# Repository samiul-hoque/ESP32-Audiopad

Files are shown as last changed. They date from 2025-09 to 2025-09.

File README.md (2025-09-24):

# ESP32-Audiopad

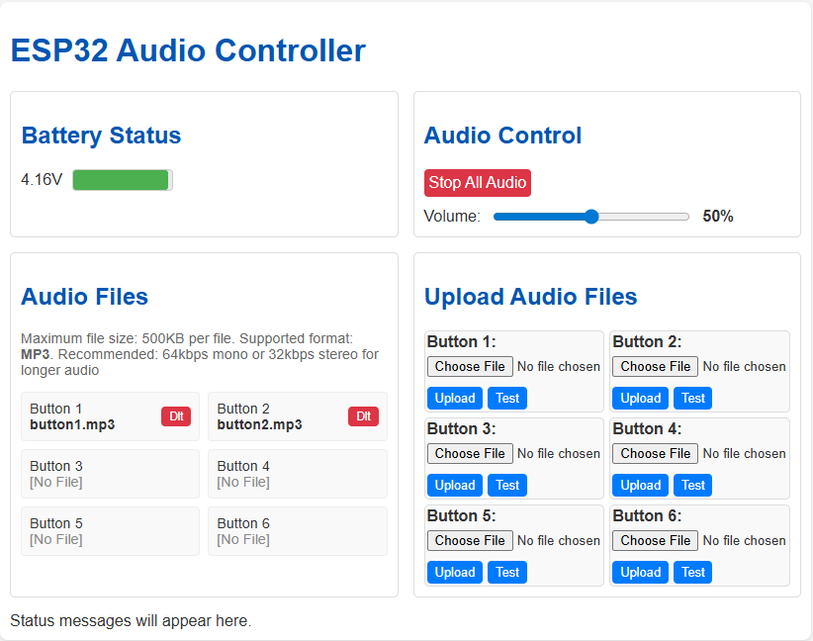
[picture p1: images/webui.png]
ESP32 Audiopad


A WiFi-enabled, web-configurable audio playback device using an ESP32. This project turns an ESP32 into a simple soundboard that plays specific MP3 files when physical buttons are pressed. All configuration, file management, and testing can be done through a web interface hosted on the device itself.

## Features

*   **6-Button Audio Playback:** Connect up to 6 physical buttons to trigger MP3 playback.
*   **Web-Based Management:** No need to re-flash to change sounds. Connect to the ESP32's web server to:
    *   Upload MP3 files for each button.
    *   Delete assigned audio files.
    *   View currently assigned files.
    *   Monitor battery voltage.
    *   Remotely test button sounds.
    *   Stop any currently playing audio.
*   **Over-The-Air (OTA) Updates:** Update the firmware and filesystem (SPIFFS) over WiFi using the Arduino IDE.
*   **Deep Sleep:** Automatically enters deep sleep after a period of inactivity to conserve battery, and wakes up on a button press.
*   **I2S Audio Output:** Uses an I2S amplifier for clear digital audio playback.
*   **Battery Monitoring:** Reads voltage from an ADC pin to provide a battery level estimate on the web UI.

## Hardware Requirements

*   **ESP32 Development Board:** Any standard ESP32 board should work.
*   **I2S Audio Amplifier:** MAX98357A has been used.
*   **Speaker:** 3W speaker.
*   **Push Buttons (x6):** Cherry MX Red buttons.
*   **Resistors:** External pull-up resistors are needed for deep sleep functionality to save battery.
*   **Battery:** 1650 Lithium Ion battery with BMS
*   **Wires and a breadboard/protoboard.**

### Pinout

The following pin connections are defined in the code.

| Component | ESP32 Pin | Description |
| --- | --- | --- |
| **I2S Amplifier** | | |
| `BCLK` | 4 | Bit Clock |
| `LRC` / `WS` | 2 | Left/Right Clock (Word Select) |
| `DIN` | 15 | Data In |
| **Buttons** | |10k External Pull-up Resistors used |
| Button 1 | 25 | |
| Button 2 | 26 | |
| Button 3 | 27 | |
| Button 4 | 13 | |
| Button 5 | 14 | |
| Button 6 | 32 | |
| **Battery** | | For voltage monitoring |
| `BATTERY_PIN` | 35 | Connect to the positive terminal |

> **Note:** The code is currently configured for buttons with external pull-up resistors (`pinMode(PIN, INPUT)`). The current debounce logic works for a button press pulling the pin LOW.

## Software Setup

1.  **Arduino IDE:** Make sure you have the Arduino IDE installed with the ESP32 board support package.

2.  **Libraries:** Install the following libraries through the Arduino Library Manager:
    *   `ESP8266Audio` by Earle F. Philhower, III (works for ESP32 as well)
    *   `WebServer` (part of the ESP32 core)
    *   `SPIFFS` (part of the ESP32 core)

3.  **WiFi Credentials:**
    *   Create a file named `secrets.h` in the same directory as your `.ino` file.
    *   Add your WiFi network credentials to this file like so:

    ```cpp
    // secrets.h
    #pragma once

    const char* ssid = "YOUR_WIFI_SSID";
    const char* password = "YOUR_WIFI_PASSWORD";
    ```
    *   The `secrets.h` file is included in `.gitignore` to prevent you from accidentally committing your credentials.

4.  **Upload Filesystem:**
    *   Before the first flash, you need to upload the filesystem image. In the Arduino IDE, go to `Tools` > `Partition Scheme` and select a scheme with SPIFFS, like "Default 4MB with spiffs (1.2MB APP/1.5MB SPIFFS)".
    *   If you have a `data` directory with files to pre-load, you can use the "ESP32 Sketch Data Upload" tool. For this project, it's not necessary as the web interface creates the `/audio` directory.

5.  **Compile and Flash:**
    *   Select your ESP32 board and COM port from the `Tools` menu.
    *   Click the "Upload" button to flash the firmware to your ESP32.

## How to Use

1.  **Power On:** Power up your ESP32. It will automatically connect to the WiFi network you specified in `secrets.h`.

2.  **Find IP Address:** Open the Arduino IDE's Serial Monitor (baud rate 115200). The ESP32 will print its IP address once connected to WiFi.

3.  **Open Web Interface:** Open a web browser on a device connected to the same network and navigate to the ESP32's IP address (e.g., `http://192.168.1.123`).

4.  **Upload Audio:**
    *   The web page will show an upload section for each of the 6 buttons.
    *   Click "Choose File" for a button, select an MP3 file from your computer, and click "Upload".
    *   The file will be named `buttonX.mp3` (where X is the button number) and stored in the ESP32's filesystem.
    *   **Note:** There is a file size limit of 500KB per file. For best results, use MP3s with a lower bitrate (e.g., 64kbps mono).

5.  **Play Sounds:**
    *   Press a physical button connected to the ESP32 to play its assigned sound.
    *   You can also use the "Test" button on the web interface to trigger playback remotely.

6.  **Manage Files:**
    *   The "Audio Files" section shows which buttons have a sound assigned.
    *   You can delete any sound file by clicking the "Delete" button next to it.

## Future Improvements
*   Add a visual indicator (e.g., an LED) to show when the device is going to sleep.
*   Implement a "Settings" page in the web UI to configure sleep timeout and other parameters.

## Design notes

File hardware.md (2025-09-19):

# Pin Definitions

## Battery
BATTERY_PIN 35
ADC_TO_VOLT 7.445f / 4096.0f 

## Buttons
buttonPins[] = {25, 26, 27, 13, 14, 32};

## Amp
BCLK = 4
LRC = 2
DIN = 15

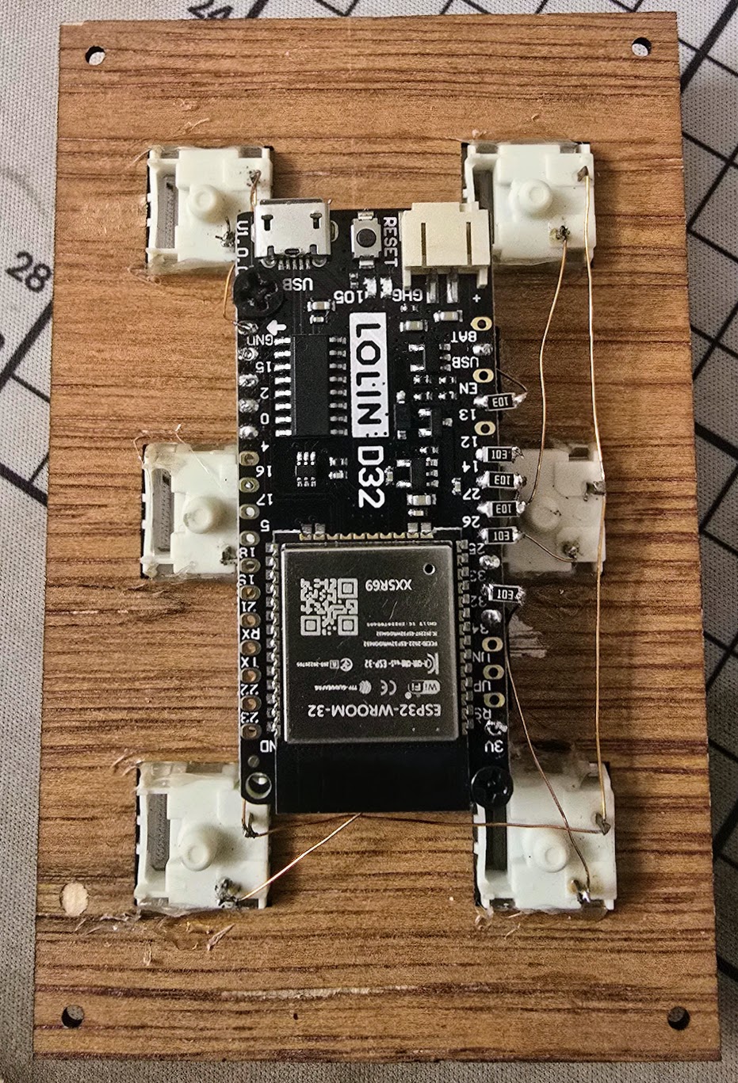
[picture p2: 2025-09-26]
images/Electronics.jpg

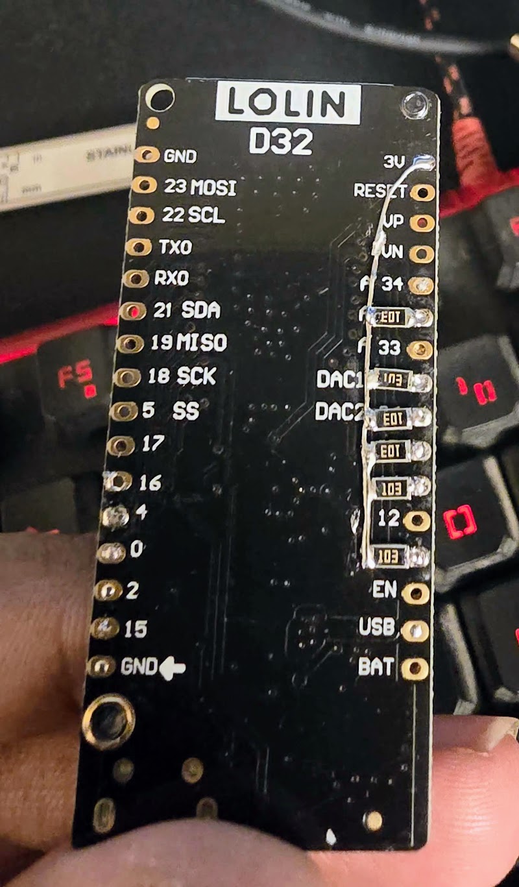
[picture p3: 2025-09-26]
images/10k external pull up resistors for RTCGPIO.jpg

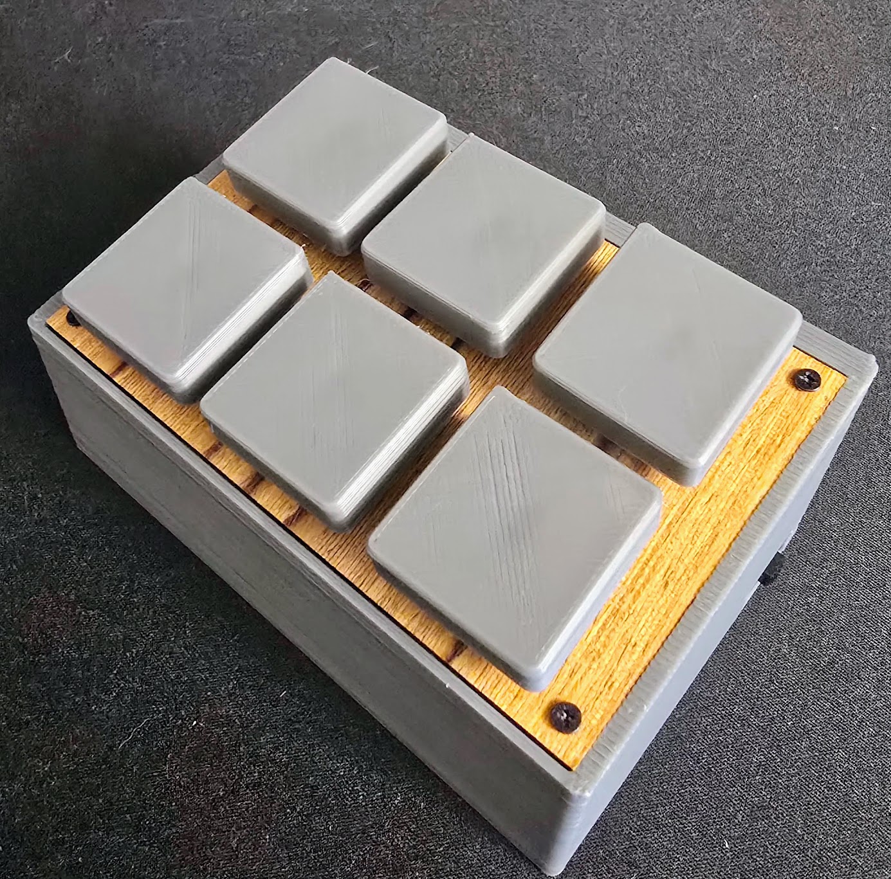
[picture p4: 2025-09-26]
images/ESP32AudioPad.jpg

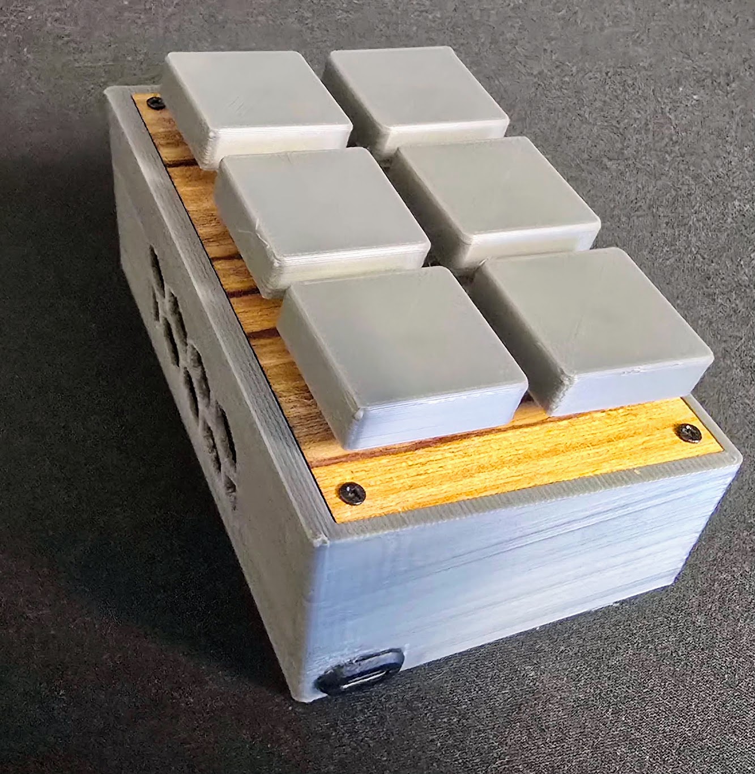
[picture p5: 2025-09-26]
images/ESP32AudioPad2.jpg

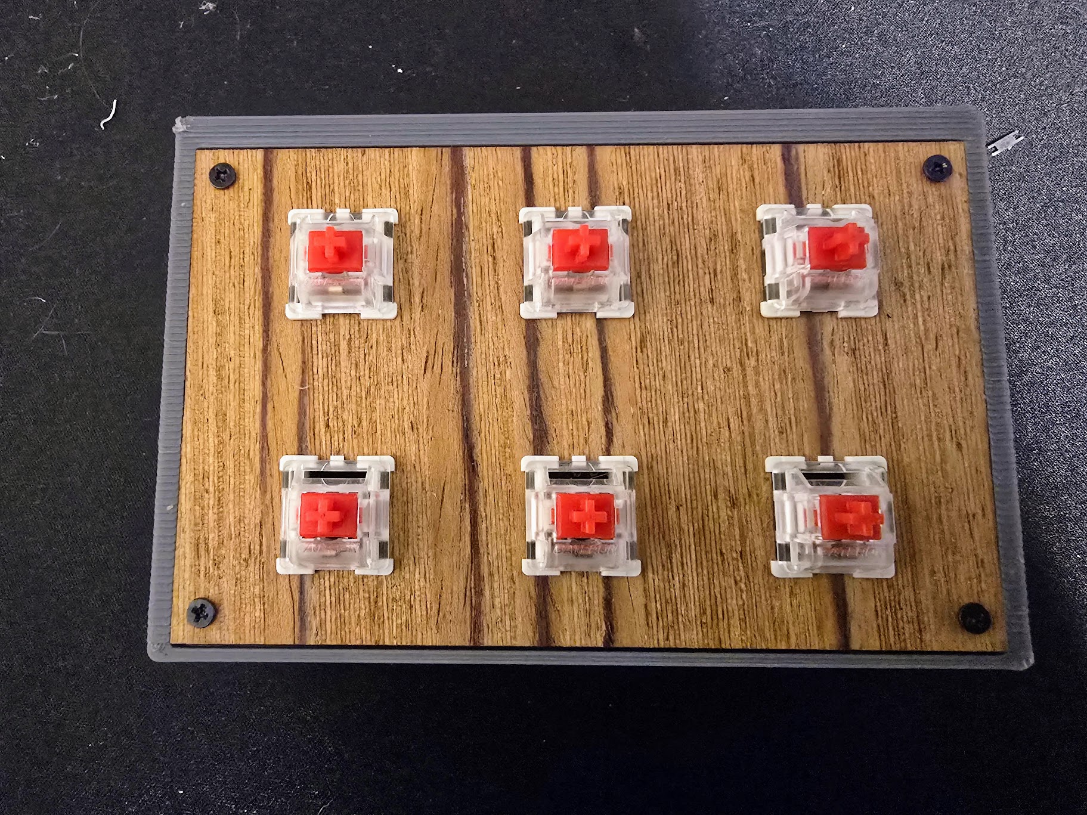
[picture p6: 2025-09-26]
images/ESP32AudioPad3.jpg

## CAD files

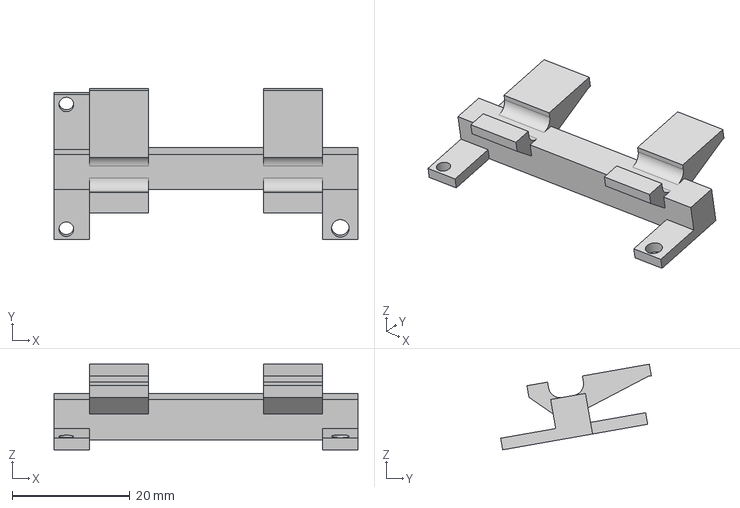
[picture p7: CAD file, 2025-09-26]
3D Files/ESP-d32 holder.step
51.6 x 25.6 x 14.5 mm

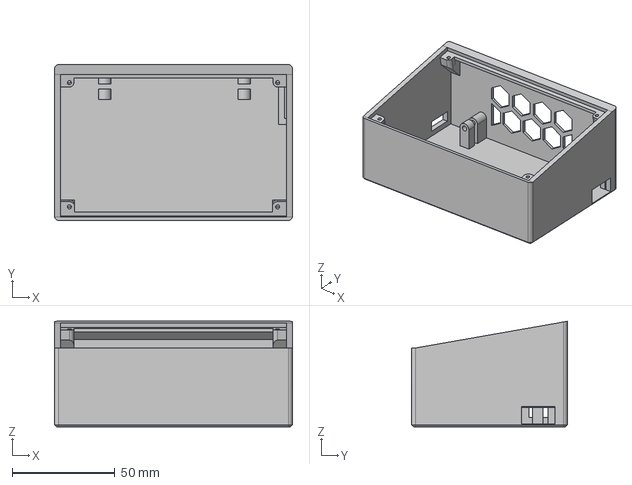
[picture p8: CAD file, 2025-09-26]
3D Files/Base.step
116.0 x 75.9 x 51.5 mm

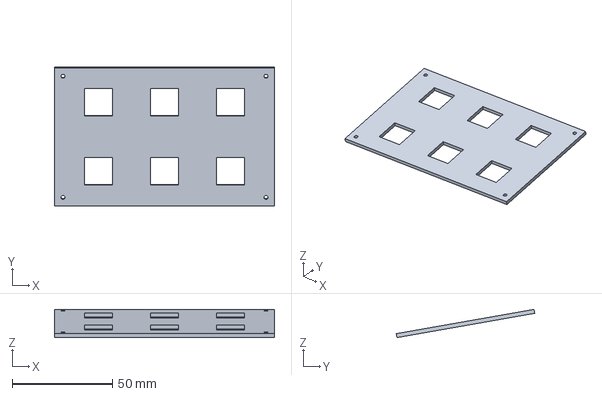
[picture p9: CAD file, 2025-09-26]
3D Files/Top.step
110.0 x 69.3 x 14.1 mm

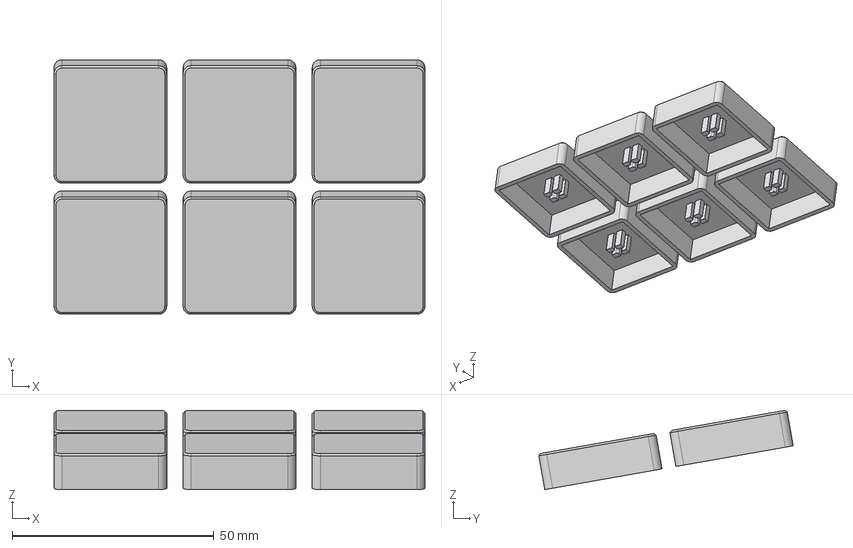
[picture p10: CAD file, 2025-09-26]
3D Files/Buttons.step
92.0 x 63.1 x 19.6 mm

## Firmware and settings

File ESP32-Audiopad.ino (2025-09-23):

#include <WiFi.h>
#include <SPIFFS.h>
#include "secrets.h"

// Include all our custom headers
#include "config.h"
#include "button_manager.h"
#include "audio_manager.h"
#include "web_server.h"
#include "ota_manager.h"
#include "power_manager.h"

// Create instances of our managers
ButtonManager buttonManager;
AudioManager audioManager;
WebServerManager webServer;
OTAManager otaManager;
PowerManager powerManager;

// Timing variables for power management
unsigned long lastActivityCheck = 0;

// Callback functions
void onButtonPressed(int buttonNum) {
    powerManager.updateActivity(); // Update activity on button press
    audioManager.playButtonSound(buttonNum);
}

void onTestButtonPressed(int buttonNum) {
    powerManager.updateActivity(); // Update activity on web test
    audioManager.playButtonSound(buttonNum);
}

void onStopAudio() {
    powerManager.updateActivity(); // Update activity on stop command
    audioManager.stopCurrentAudio();
}

void onSetVolume(float volume) {
    powerManager.updateActivity(); // Update activity on volume change
    audioManager.setVolume(volume);
}

float onGetVolume() {
    powerManager.updateActivity(); // Update activity on volume request
    return audioManager.getVolume();
}

void setup() {
    Serial.begin(115200);
    
    // Initialize power management first (handles wake up reasons)
    powerManager.init();
    
    // Initialize SPIFFS
    if(!SPIFFS.begin(true)) {
        Serial.println("SPIFFS Mount Failed");
        return;
    }
    
    // Create audio directory if it doesn't exist
    if (!SPIFFS.exists("/audio")) {
        SPIFFS.mkdir("/audio");
    }

    // Print SPIFFS info
    size_t totalBytes = SPIFFS.totalBytes();
    size_t usedBytes = SPIFFS.usedBytes();
    Serial.printf("SPIFFS Total: %d bytes, Used: %d bytes, Free: %d bytes\n", 
                  totalBytes, usedBytes, totalBytes - usedBytes);
    
    // Initialize battery pin
    pinMode(BATTERY_PIN, INPUT);
    
    // Initialize all managers
    buttonManager.init();
    audioManager.init();
    
    // Set up button callback
    buttonManager.onButtonPressed = onButtonPressed;
    
    // Connect to WiFi
    WiFi.begin(ssid, password);
    while (WiFi.status() != WL_CONNECTED) {
        delay(1000);
        Serial.println("Connecting to WiFi...");
    }
    Serial.println("WiFi connected!");
    Serial.print("IP address: ");
    Serial.println(WiFi.localIP());
    
    // Update activity after WiFi connection
    powerManager.updateActivity();
    
    // Initialize OTA and web server
    otaManager.init();
    webServer.init();
    
    // Set up web server callbacks
    webServer.setTestButtonCallback(onTestButtonPressed);
    webServer.setStopAudioCallback(onStopAudio);
    webServer.setVolumeCallbacks(onSetVolume, onGetVolume);
    
    Serial.println("System initialized successfully!");
    Serial.printf("Deep sleep will activate after %lu seconds of inactivity\n", SLEEP_TIMEOUT_MS / 1000);
}

void loop() {
    // Handle all the different components
    otaManager.handle();
    
    // Update activity on any web server interaction
    static bool hadWebActivity = false;
    webServer.handleClient();
    // Note: We could implement a more sophisticated web activity detection
    // by modifying the web server to report when it handles requests
    
    audioManager.update();
    buttonManager.checkButtons();
    
    // Periodically check sleep conditions
    unsigned long currentTime = millis();
    if (currentTime - lastActivityCheck >= ACTIVITY_UPDATE_INTERVAL) {
        lastActivityCheck = currentTime;
        
        // Check if we should enter deep sleep
        powerManager.checkSleepConditions(audioManager.getIsPlaying());
        
        // Optional: Print activity status for debugging
        if (powerManager.getTimeSinceActivity() > 60000) { // Only after 1 minute
            unsigned long timeLeft = (SLEEP_TIMEOUT_MS - powerManager.getTimeSinceActivity()) / 1000;
            if (timeLeft < 60) { // Only print when close to sleep
                Serial.printf("Time until sleep: %lu seconds\n", timeLeft);
            }
        }
    }
    
    delay(10);
}

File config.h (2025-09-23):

#ifndef CONFIG_H
#define CONFIG_H

// Hardware pin definitions
const int BUTTON_PINS[] = {13, 14, 27, 26, 25, 32};
const int BATTERY_PIN = 35;

// Battery voltage conversion
const float ADC_TO_VOLT = 7.285f / 4096.0f;    

// File size limit (in bytes)
const size_t MAX_FILE_SIZE = 500000; // 500KB per file

// Button debouncing
const unsigned long DEBOUNCE_DELAY = 50;

// Audio gain settings (0.0 to 1.0)
const float DEFAULT_AUDIO_GAIN = 0.5;
const float MIN_AUDIO_GAIN = 0.0;
const float MAX_AUDIO_GAIN = 1.0;

// I2S audio pins
const int I2S_BCLK_PIN = 4;
const int I2S_LRC_PIN = 2;
const int I2S_DIN_PIN = 15;

// Battery update interval (milliseconds)
const unsigned long BATTERY_UPDATE_INTERVAL = 10000;

// Number of buttons
const int NUM_BUTTONS = 6;

// Power management settings
const unsigned long SLEEP_TIMEOUT_MS = 300000;        // 5 minutes (300,000ms) - configurable sleep timeout
const unsigned long SLEEP_WARNING_TIME_MS = 30000;    // 30 seconds warning before sleep
const unsigned long ACTIVITY_UPDATE_INTERVAL = 5000;  // Check activity every 5 seconds

#endif

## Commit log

2025-09-22 Refactor and modularize ESP32 audio pad firmware
    Replaces esp_audio_device.ino with a modular structure, introducing separate headers for audio, button, OTA, and web server management. Adds config.h for hardware and system constants, and web_interface.h for HTML/CSS. Improves maintainability and extensibility by separating concerns and enabling easier updates to individual components.
    Added volume slider
    [ESP32-Audiopad.ino, config.h]
2025-09-22 Refactor ButtonManager and add volume control to AudioManager
    Separated button handling logic into a new ButtonManager class with debounced button checking and callback support. AudioManager now supports setting and getting volume, with volume changes applied t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
2025-09-22 Revamp web UI and update hardware documentation
    Redesigned the web interface for improved usability and modern appearance, including a new layout, enhanced file management, and better status feedback. Updated README hardware requirements and pinout for accuracy. Changed button pin order in config.h to match new documentation.
    [config.h]
2025-09-22 Simplify button labels and update upload grid layout
    Removed pin numbers from button labels for clarity and consistency. Adjusted the upload grid to use two columns on wider screens and ensured file input styling is consistent. Also updated the page ti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
2025-09-23 Add power management with deep sleep support
    Introduces a PowerManager class to handle inactivity-based deep sleep, including wakeup via button presses. Integrates power management into the main application, adds related configuration options, 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
2025-09-24 Update README with new features and add web UI image
    Added a photo of the ESP32 Audiopad and a screenshot of the web UI to the documentation. Updated the README to mention the new deep sleep feature and revised the future improvements section to reflec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
2025-09-26 Add 3D model STEP files and hardware images
    Added STEP files for Base, Buttons, ESP-d32 holder, and Top in the '3D Files' directory. Also added several hardware reference images to the 'images' directory for documentation and assembly referenc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
    [Base.step, Buttons.step, ESP-d32 holder.step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]
